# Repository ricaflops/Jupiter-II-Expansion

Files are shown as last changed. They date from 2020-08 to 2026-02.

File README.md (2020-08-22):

# Jupiter-II Expansion
An Expansion board for the [Jupiter-II](https://github.com/ricaflops/Jupiter-II) computer

## Expands Jupiter-II with
- Video color: 16 colors, RGB output
- Programmable Sound Generator
- 128K RAM: paged
- 16K ROM: FORTH vocabulary extension
- Serial Interface

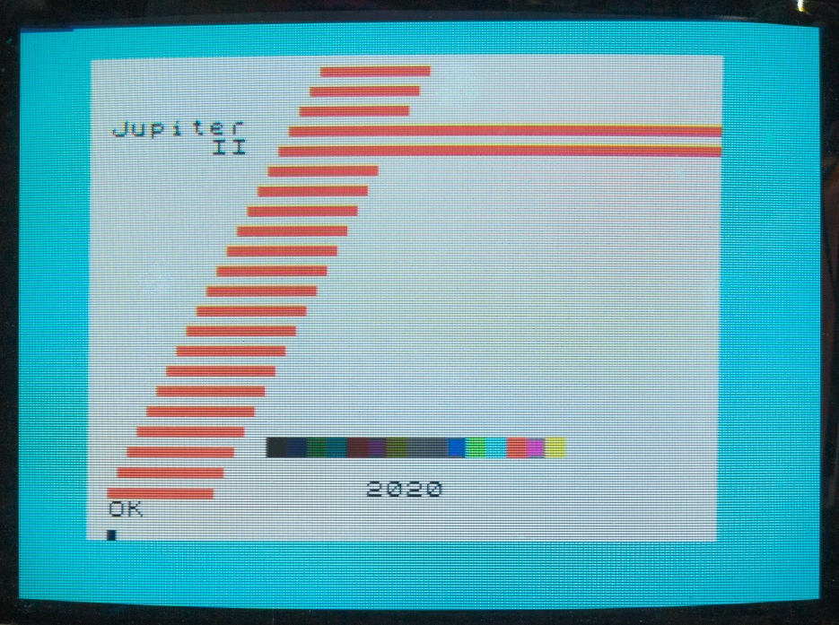
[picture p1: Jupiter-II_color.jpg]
Jupiter-II Color Screen


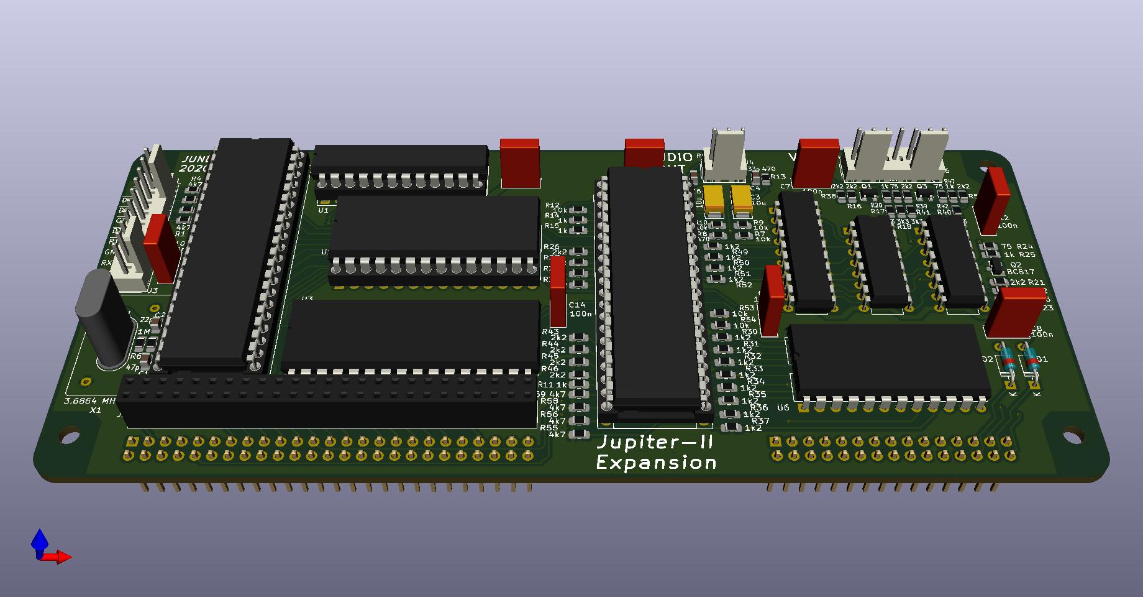
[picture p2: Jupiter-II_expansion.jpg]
Jupiter-II Expansion KiCAD 3D view


## FORTH code examples

### Colors
```
CYAN BORDER ( Change screen border color )
WHITE PAPER ( Set char background color )
BLUE DARK INK ( Set char foreground color ) 

: COLORBAR
  CLS 10 8 AT 16 0
  DO
   I INK 144 EMIT
  LOOP 
  BLACK INK
  ;
COLORBAR ( Show a colorfull bar )
```

### Memory/Screen/Font Paging
```
0 FONT  ( select alternative character set )
1 FONT  ( select original character set )

0 SCREEN ( select screen page 0 )
1 SCREEN ( select screen page 1 )

0 MPAGE ( select memory page 0 )
3 MPAGE ( select memory page 3 )
```

### Sounds
```
: PING
  200 0 PSG!
  254 7 PSG!
  16 8 PSG!
  20 12 PSG!
  1 13 PSG!
;

: SHOT
  8 6 PSG!
  247 7 PSG!
  16 8 PSG!
  20 12 PSG!
  1  13 PSG!
;
```

### Serial Comm Port
8 data bits, 1 stop bit, no parity.
```
CREATE BUFFER 256 ALLOT ( Create and Allocate a memory space to work )
: CLRBUF BUFFER 256 32 FILL ; ( Clear Buffer )
: PRTBUF CR 256 0 DO BUFFER I + EMIT LOOP CR ; ( Print Buffer )

9600 BAUD     ( set communication baud rate )
CLRBUF        ( Clear Buffer )
BUFFER 256 RX ( Receive 256 bytes from serial line )
PRTBUF        ( View received data )
BUFFER 256 TX ( Transmit 256 bytes over serial line )
```
*Note: use Space key to abort communication if needed*

# Extra FORTH vocabulary
The extended vocabulary is copied from XROM to a unused 1K RAM area at $3000-$33FF of Jupiter-II during initialization.
That allows safe memory paging while keeping the extra Words accessible.

### Standard FORTH words

```
COUNT ( addr -- addr+1 c )  Extract String length
+! ( n addr -- )  Add 'n' to 'addr' variable
? ( addr -- )  Print variable value
CMOVE ( addr1 addr2 n -- )  Copy 'n' bytes from 'addr1' to 'addr2'
FILL  ( addr n c -- )  Fill 'n' bytes with 'c' starting from 'addr'
DEPTH ( -- n )  Data Stack Depth
HEX   ( -- )  Set numeric base to Hexadecimal
```

### Programmable Sound Generator

```
PSG! ( c reg -- ) Write 'c' to PSG register 'reg'
PSG@ ( reg -- c ) Read PSG register 'reg' contents
```

### Colors

```
BORDER ( c -- ) Set screen BORDER to color 'c' , 0 to 15
INK    ( c -- ) Set character INK to color 'c' , 0 to 15
PAPER  ( c -- ) Set character PAPER to color 'c' , 0 to 15
BLACK  ( -- c ) Stack color code for Black
GREY   ( -- c ) Stack color code for Grey
BLUE   ( -- c ) Stack color code for Blue
GREEN  ( -- c ) Stack color code for Green
CYAN   ( -- c ) Stack color code for Cyan
RED    ( -- c ) Stack color code for Red
PURPLE ( -- c ) Stack color code for Purple
YELLOW ( -- c ) Stack color code for Yellow
WHITE  ( -- c ) Stack color code for White
DARK   ( c1 -- c2 ) Change color code on stack to a darker tone
```

### Serial Communication
8 data bits, 1 stop bit, no parity.

```
BAUD ( n --  )  Set UART to Baud rate 'n'
TX ( addr n --  )  Transmit 'n' bytes starting from 'addr' to serial line
RX ( addr n --  )  Receive 'n' bytes from serial line to memory 'addr'
```

Avoid transfering to/from video RAM using video circuit priority addressing. That prevents transfer speeds above 1200 bauds.
- Video RAM from $2400 to $27FF. Use mirror addressing $2000 to $23FF instead (CPU priority).
- Character Genrator RAM from $2C00 to $2FFF. Use mirror addressing $2800 to $2BFF instead (CPU priority).

*Note: Character Generator RAM is write only*

### Memory Paging
```
MPAGE  ( c -- ) Select memory page 'c' , 0 to 3
SCREEN ( c -- ) Select Screen page 'c' , 0 or 1
FONT   ( c -- ) Select character set 'c' , 0 or 1
```
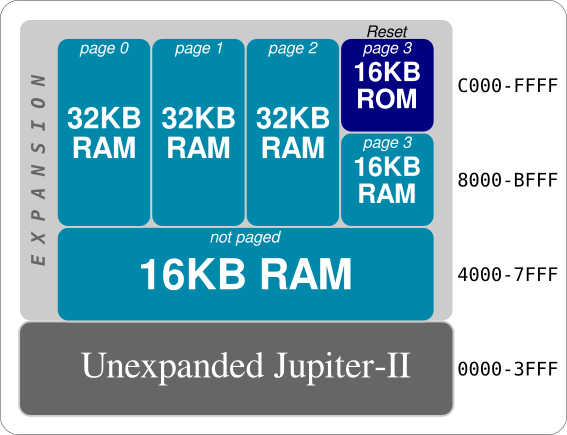
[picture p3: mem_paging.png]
Memry Paging


*Note: System resets to page 3*

## Programmable Sound Generator Registers
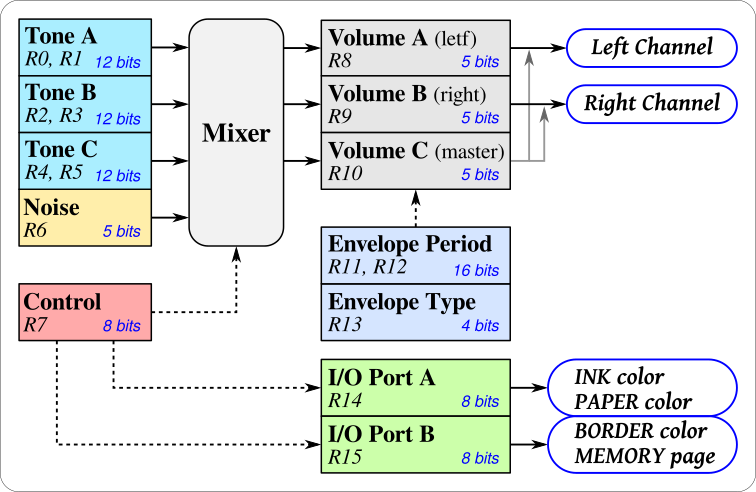
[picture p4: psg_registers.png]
Programmable Sound Generator Registers


```
   bits: 76543210 76543210
  R1 R0: ----tttt tttttttt : Tone generator A period (12-bits) 0-4095
  R3 R2: ----tttt tttttttt : Tone generator B period (12-bits) 0-4095
  R5 R4: ----tttt tttttttt : Tone generator C period (12-bits) 0-4095
     R6:          ---ttttt : Noise generator period  (5-bits)  0-31
     R7:          ppcbaCBA : I/O port and sound channel enablers
     R8:          ---Mvvvv : Channel A Volume (v) and Envelope Mode (M)
     R9:          ---Mvvvv : Channel B Volume (v) and Envelope Mode (M)
    R10:          ---Mvvvv : Channel C Volume (v) and Envelope Mode (M)
R12 R11: tttttttt tttttttt : Envelope period (16-bits) 0-65535
    R13:          ----calh : Envelope Shape: Continue (c), Attack (a), Alternate(l), Hold (h)
    R14:          dddddddd : I/O Port-A data
    R15:          dddddddd : I/O Port-B data
```

**R0..R6**: Tone and Noise Period (Frequency) settings<br/>
> t = 203125 / f , where f is the desirable frequency in Hz<br/>
> Tone Range: 49.6 Hz to 203.1 kHz (0..4095)<br/>
> Noise Range: 6.55 kHz to 293.1 kHz (0..31)<br/>

**R7**: Tone and Noise Mixer and I/O Ports direction<br/>
- bit0: when 0 enables tone A on channel A, 1 disables it
- bit1: when 0 enables tone B on channel B, 1 disables it
- bit2: when 0 enables tone C on channel C, 1 disables it
- bit3: when 0 enables Noise on channel A, 1 disables it
- bit4: when 0 enables Noise on channel B, 1 disables it
- bit5: when 0 enables Noise on channel C, 1 disables it
- bit6: when 0 set digital Port-A as input, 1 set it as output
- bit7: when 0 set digital Port-B as input, 1 set it as output<br/>

**R8..R10**: Channel volume<br/>
- bit4  : when 0 volume is fixed, when 1 volume is Envelope controlled
- bit3-0: Fixed volume value (0-31)<br/>

**R11, R12**: Envelope period<br/>
> t = s / 78.769e-6 , where s is the desirable period in seconds<br/>
> Period range: 78.8 us to 5.16 seconds<br/>

**R13**: Envelope Shape combination<br/>
- bit3: Continue: when 1 follows Hold setting, when 0 resets down after one cycle
- bit2: Attack: when 1 attack ramps up, when 0 ramps down
- bit1: Alternate: when 1 envelope shape reverses on each cycle (up/down)
- bit0: Hold: when 1 limits to one cycle and sustain final value<br/>

**R14, R15**: Digital I/O Port data<br/>
- Port A (register 14) controls PAPER and INK colors
- Port B (register 15) controls BORDER color and paging<br/>

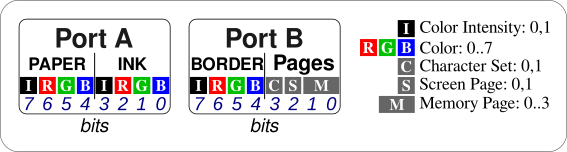
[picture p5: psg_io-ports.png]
Programmable Sound Generator Ports


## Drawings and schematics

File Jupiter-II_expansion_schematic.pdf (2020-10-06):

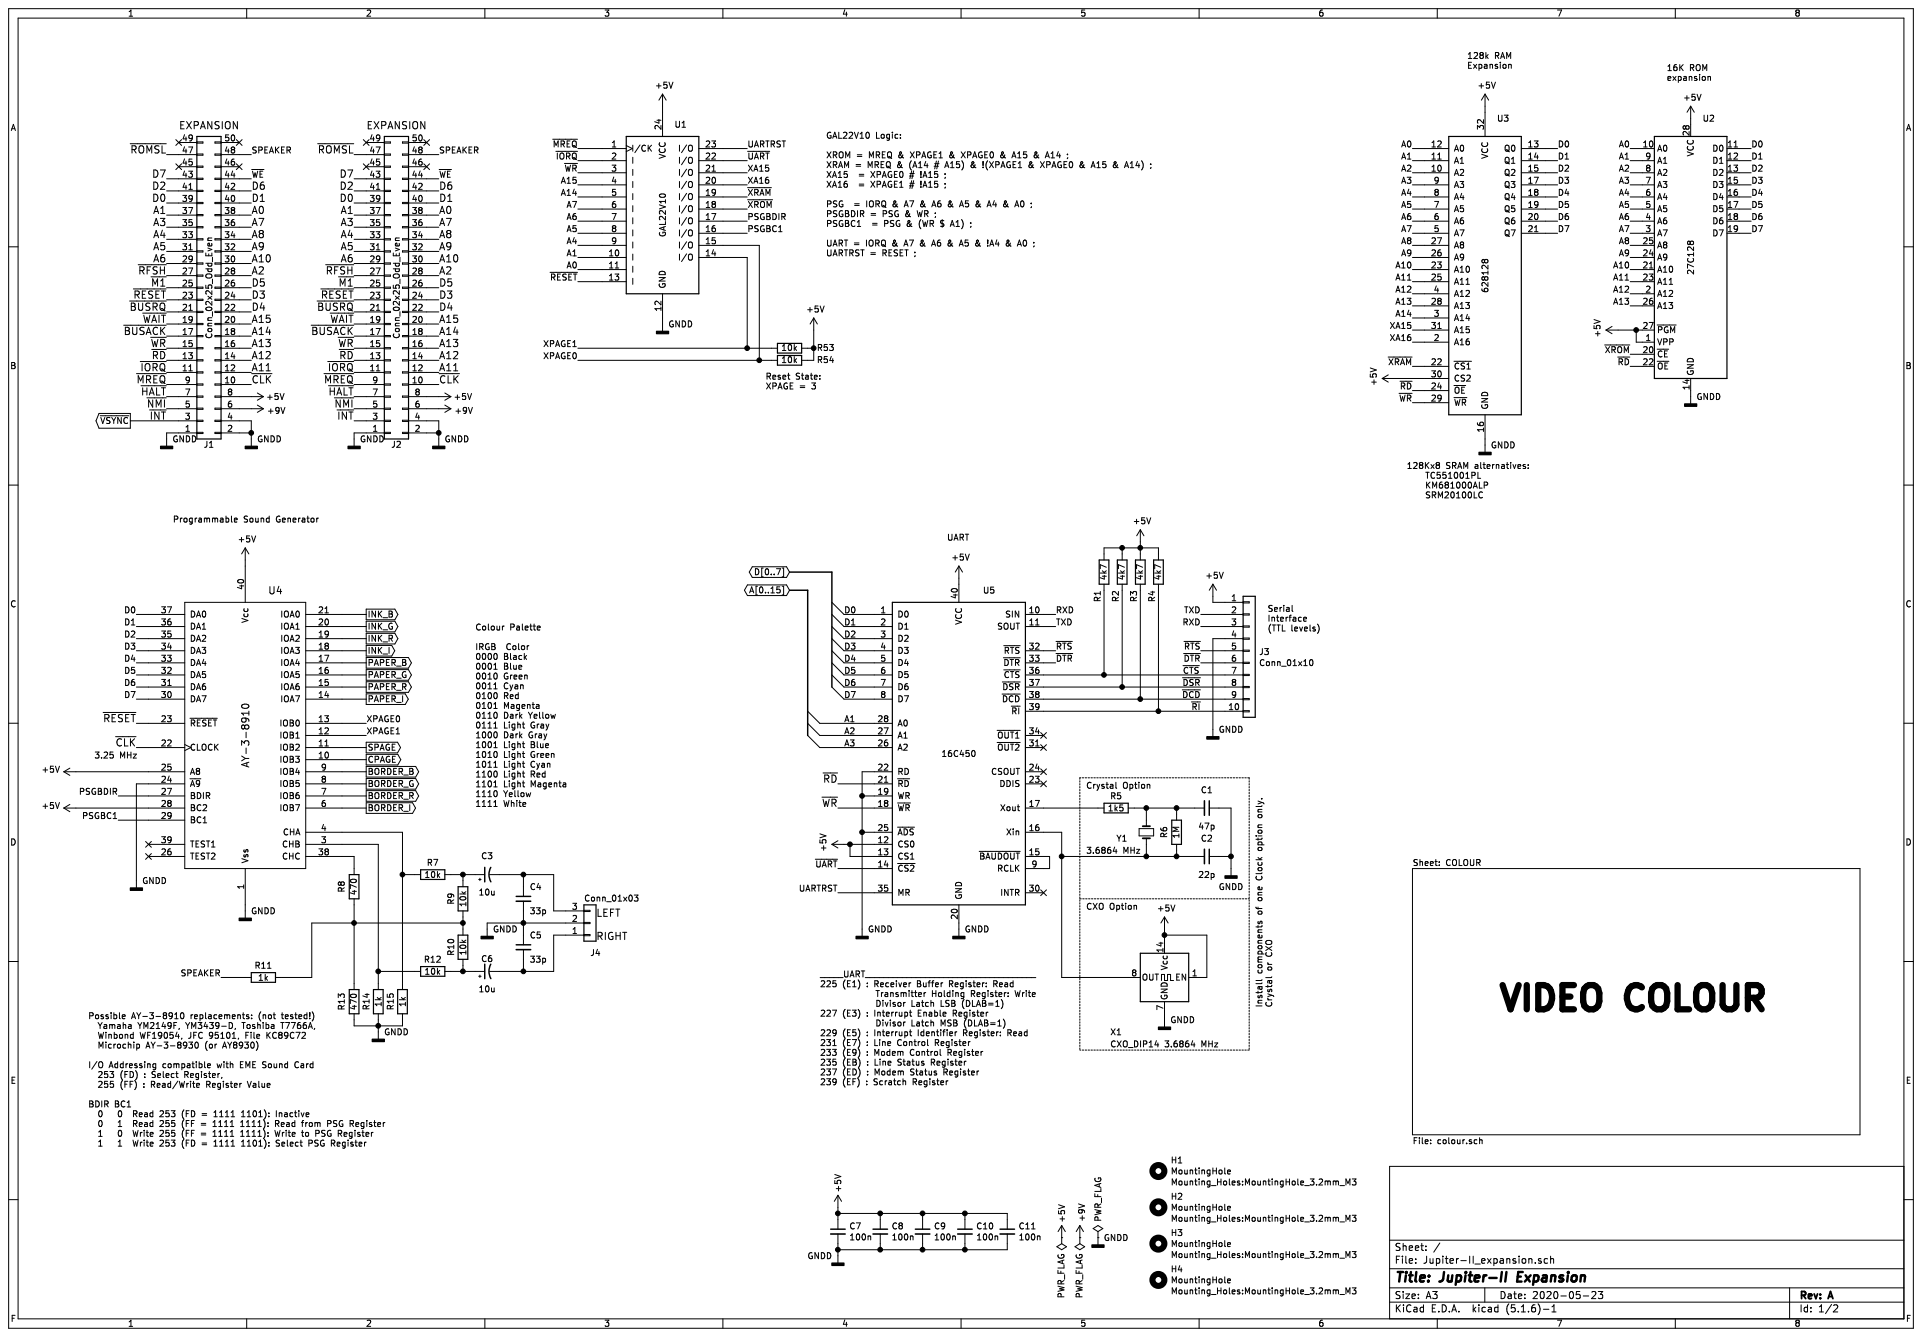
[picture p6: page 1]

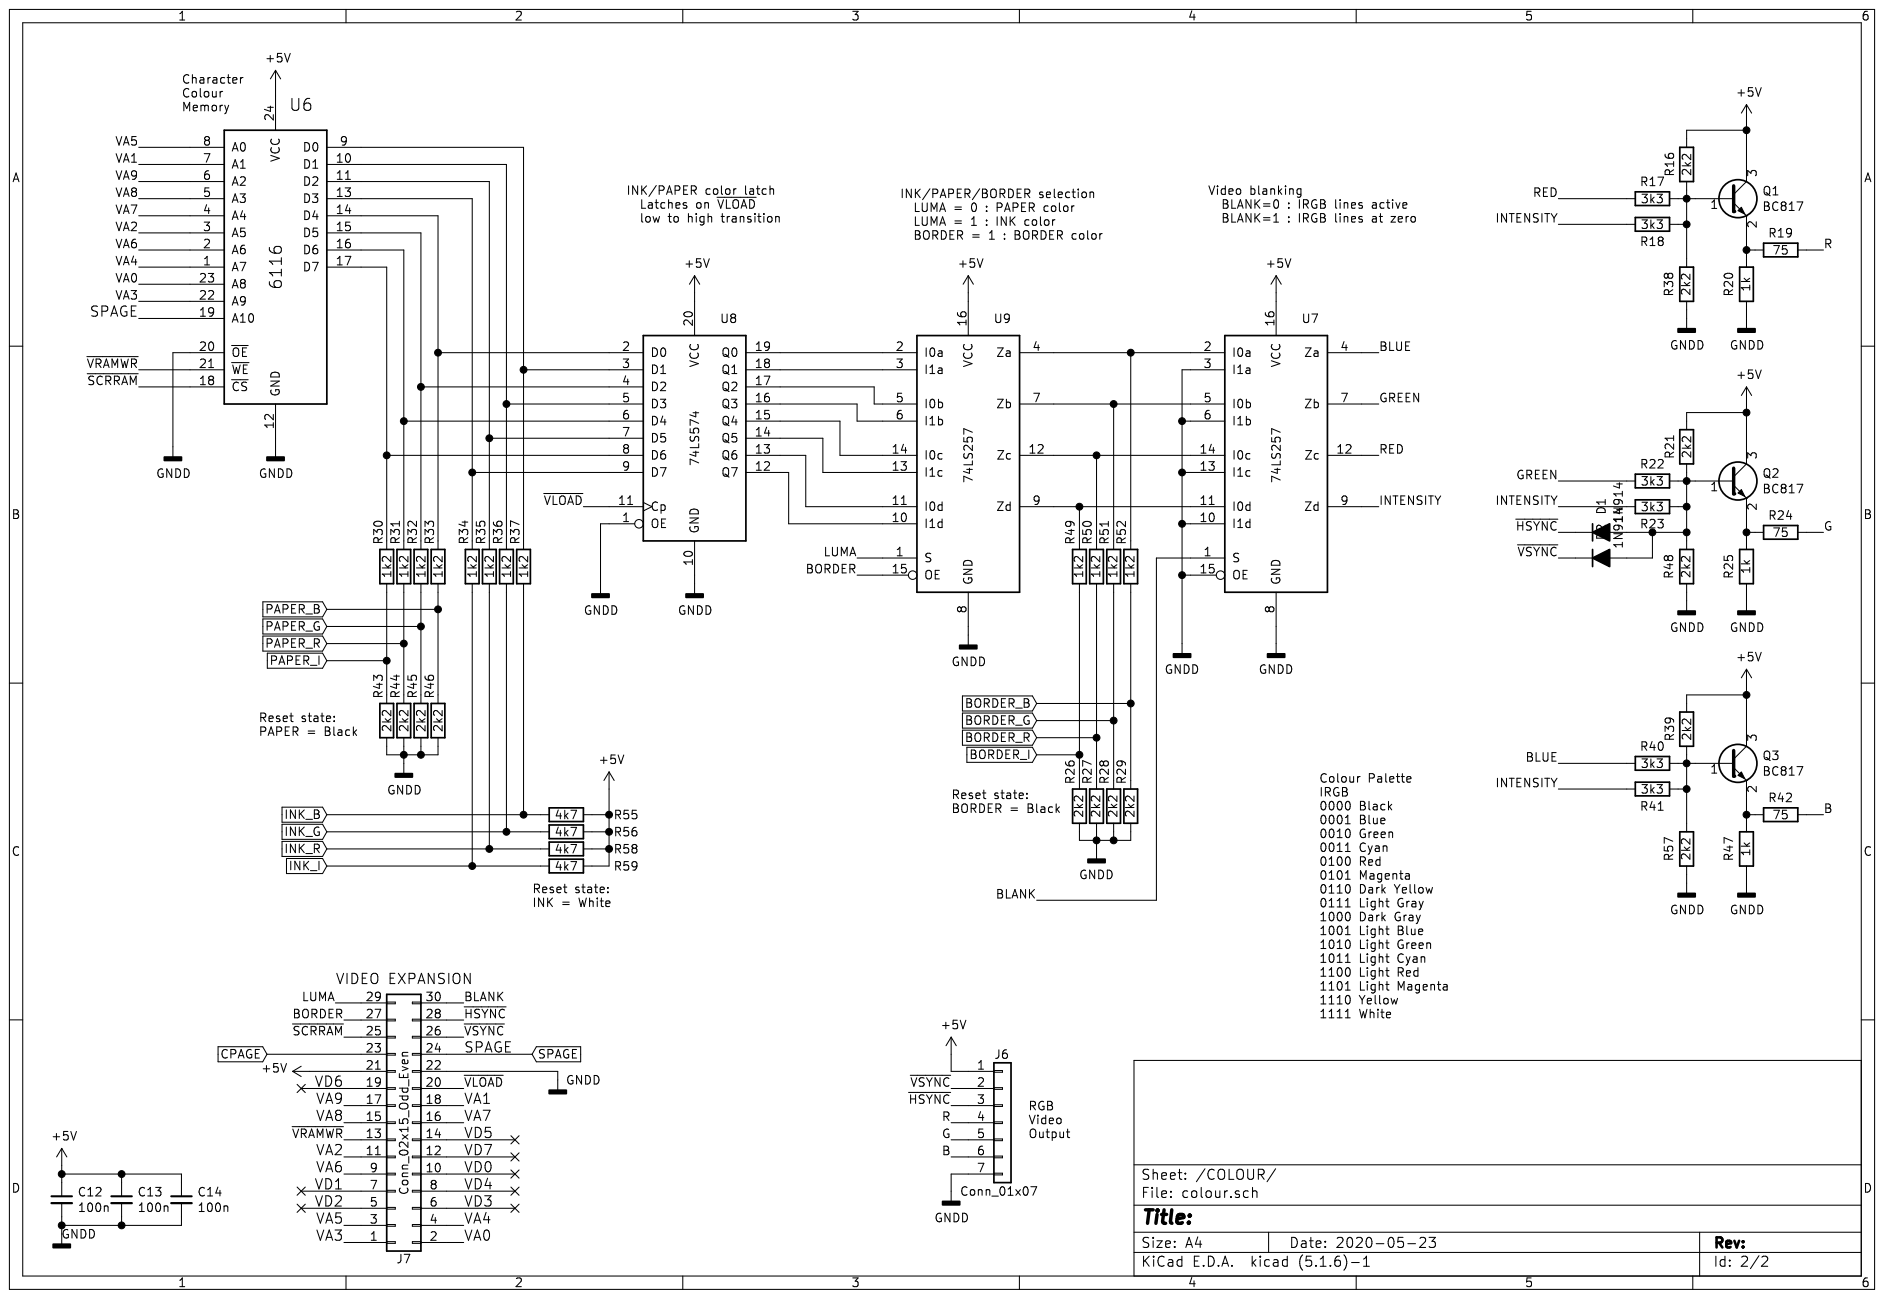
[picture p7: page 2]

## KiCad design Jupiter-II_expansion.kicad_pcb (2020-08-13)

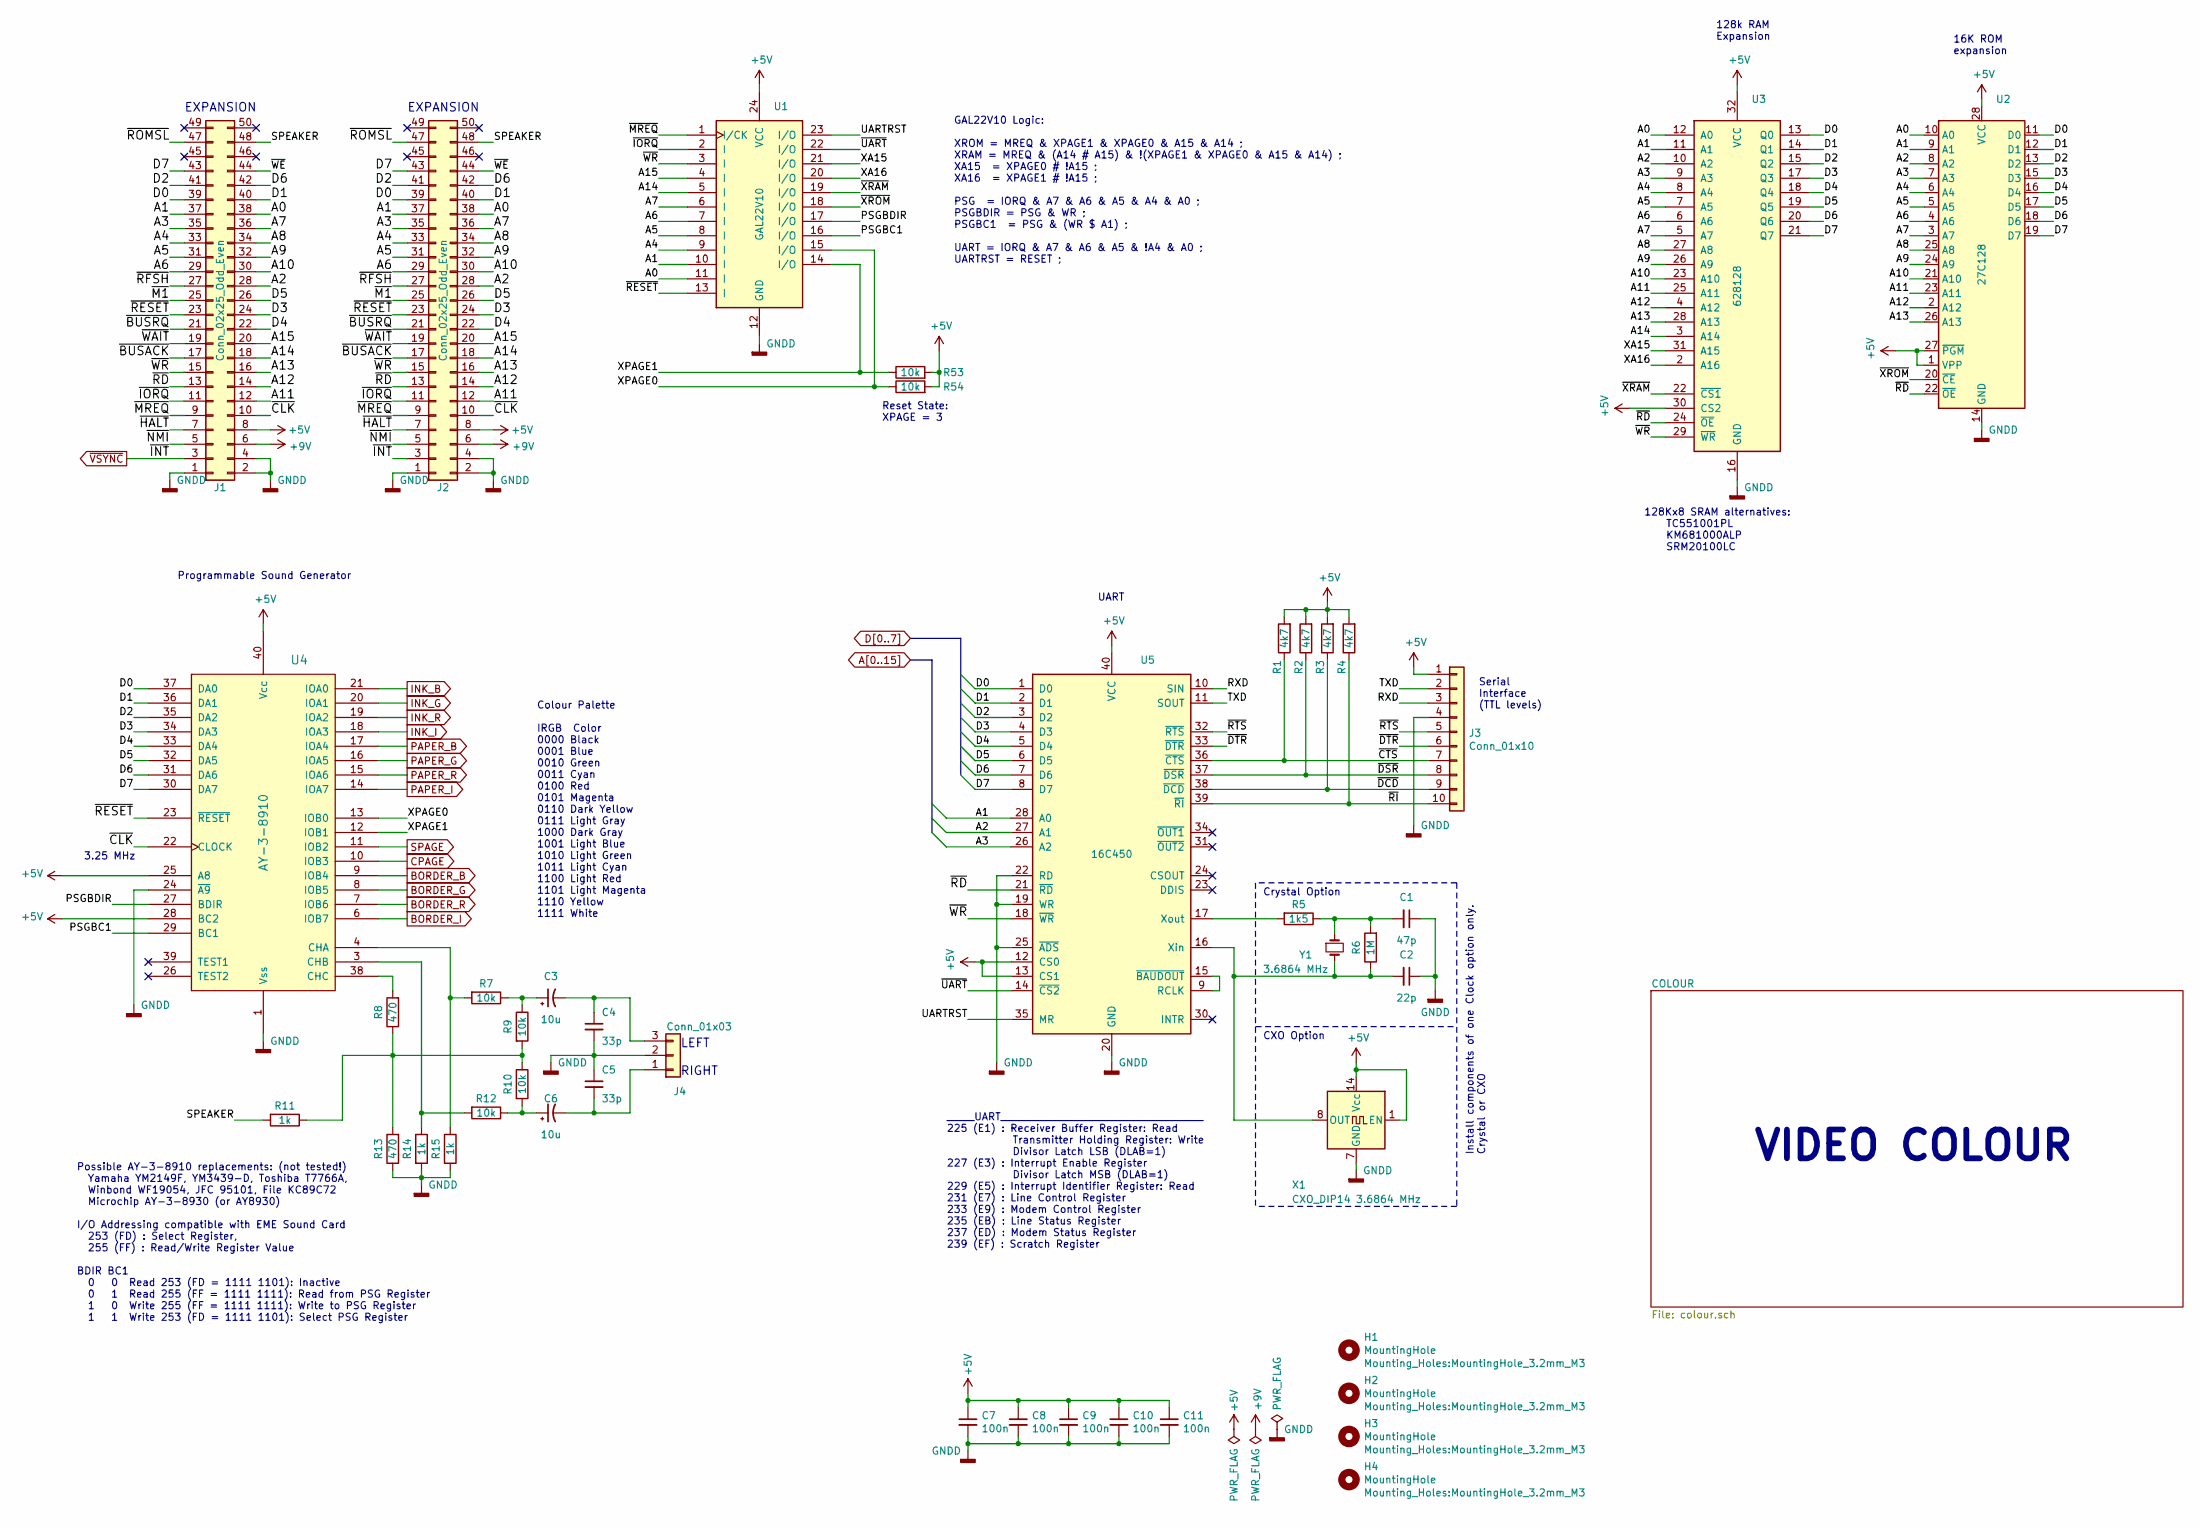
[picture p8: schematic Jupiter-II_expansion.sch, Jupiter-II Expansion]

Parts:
C1: 47p; C_0805_2012Metric_Pad1.15x1.40mm_HandSolder
C2: 22p; C_0805_2012Metric_Pad1.15x1.40mm_HandSolder
C3, C6: 10u; CP_EIA-6032-15_Kemet-U_Pad2.25x2.35mm_HandSolder
C4, C5: 33p; C_0805_2012Metric_Pad1.15x1.40mm_HandSolder
C7, C8, C9, C10, C11: 100n; C_Rect_L7.0mm_W2.5mm_P5.00mm
H1, H2, H3, H4: MountingHole; MountingHole_3.2mm_M3
J1: Conn_02x25_Odd_Even; PinHeader_2x25_P2.54mm_Vertical
J2: Conn_02x25_Odd_Even; PinSocket_2x25_P2.54mm_Vertical
J3: Conn_01x10; Molex_KK-254_AE-6410-10A_1x10_P2.54mm_Vertical
J4: Conn_01x03; Molex_KK-254_AE-6410-03A_1x03_P2.54mm_Vertical
R1, R2, R3, R4: 4k7; R_0805_2012Metric_Pad1.15x1.40mm_HandSolder
R5: 1k5; R_0805_2012Metric_Pad1.15x1.40mm_HandSolder
R6: 1M; R_0805_2012Metric_Pad1.15x1.40mm_HandSolder
R7, R9, R10, R12, R53, R54: 10k; R_0805_2012Metric_Pad1.15x1.40mm_HandSolder
R8, R13: 470; R_0805_2012Metric_Pad1.15x1.40mm_HandSolder
R11, R14, R15: 1k; R_0805_2012Metric_Pad1.15x1.40mm_HandSolder
U1: GAL22V10; DIP-24_W7.62mm_Socket
U2: 27C128; DIP-28_W15.24mm
U3: 628128; DIP-32_W15.24mm
U4: AY-3-8910; DIP-40_W15.24mm_Socket
U5: 16C450; DIP-40_W15.24mm_Socket
X1: CXO_DIP14 3.6864 MHz; Oscillator_DIP-14
Y1: 3.6864 MHz; Crystal_HC18-U_Vertical

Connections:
+5V: C7.1, C8.1, C9.1, C10.1, C11.1, J1.8, J2.8, J3.1, R1.2, R2.2, R3.2, R4.2, R53.2, R54.2, U1.24 (VCC), U2.1 (VPP), U2.27 (~PGM), U2.28 (VCC), U3.30 (CS2), U3.32 (VCC), U4.25 (A8), U4.28 (BC2), U4.40 (Vcc), U5.12 (CS0), U5.13 (CS1), U5.40 (VCC), X1.1 (EN), X1.14 (Vcc); also elsewhere on the board
+9V: J1.6, J2.6
/PSGBC1: U1.16 (I/O), U4.29 (BC1)
/PSGBDIR: U1.17 (I/O), U4.27 (BDIR)
/RXD: J3.3, U5.10 (SIN)
/SPEAKER: J1.48, J2.48, R11.2
/TXD: J3.2, U5.11 (SOUT)
/UARTRST: U1.23 (I/O), U5.35 (MR)
/XA15: U1.21 (I/O), U3.31 (A15)
/XA16: U1.20 (I/O), U3.2 (A16)
/XPAGE0: R54.1, U1.15 (I/O), U4.13 (IOB0)
/XPAGE1: R53.1, U1.14 (I/O), U4.12 (IOB1)
/~BUSACK: J1.17, J2.17
/~BUSRQ: J1.21, J2.21
/~CLK: J1.10, J2.10, U4.22 (CLOCK)
/~CTS: J3.7, R1.1, U5.36 (~CTS)
/~DCD: J3.9, R3.1, U5.38 (~DCD)
/~DSR: J3.8, R2.1, U5.37 (~DSR)
/~DTR: J3.6, U5.33 (~DTR)
/~HALT: J1.7, J2.7
/~IORQ: J1.11, J2.11, U1.2 (I)
/~M1: J1.25, J2.25
/~MREQ: J1.9, J2.9, U1.1 (I/CK)
/~NMI: J1.5, J2.5
/~RD: J1.13, J2.13, U2.22 (~OE), U3.24 (~OE), U5.21 (~RD)
/~RESET: J1.23, J2.23, U1.13 (I), U4.23 (~RESET)
/~RFSH: J1.27, J2.27
/~RI: J3.10, R4.1, U5.39 (~RI)
/~ROMSL: J1.47, J2.47
/~RTS: J3.5, U5.32 (~RTS)
/~UART: U1.22 (I/O), U5.14 (~CS2)
/~WAIT: J1.19, J2.19
/~WE: J1.44, J2.44
/~WR: J1.15, J2.15, U1.3 (I), U3.29 (~WR), U5.18 (~WR)
/~XRAM: U1.19 (I/O), U3.22 (~CS1)
/~XROM: U1.18 (I/O), U2.20 (~CE)
A0: J1.38, J2.38, U1.11 (I), U2.10 (A0), U3.12 (A0)
A1: J1.37, J2.37, U1.10 (I), U2.9 (A1), U3.11 (A1), U5.28 (A0)
A2: J1.28, J2.28, U2.8 (A2), U3.10 (A2), U5.27 (A1)
A3: J1.35, J2.35, U2.7 (A3), U3.9 (A3), U5.26 (A2)
A4: J1.33, J2.33, U1.9 (I), U2.6 (A4), U3.8 (A4)
A5: J1.31, J2.31, U1.8 (I), U2.5 (A5), U3.7 (A5)
A6: J1.29, J2.29, U1.7 (I), U2.4 (A6), U3.6 (A6)
A7: J1.36, J2.36, U1.6 (I), U2.3 (A7), U3.5 (A7)
A8: J1.34, J2.34, U2.25 (A8), U3.27 (A8)
A9: J1.32, J2.32, U2.24 (A9), U3.26 (A9)
A10: J1.30, J2.30, U2.21 (A10), U3.23 (A10)
A11: J1.12, J2.12, U2.23 (A11), U3.25 (A11)
A12: J1.14, J2.14, U2.2 (A12), U3.4 (A12)
A13: J1.16, J2.16, U2.26 (A13), U3.28 (A13)
A14: J1.18, J2.18, U1.5 (I), U3.3 (A14)
A15: J1.20, J2.20, U1.4 (I)
BORDER_B: U4.9 (IOB4); also elsewhere on the board
BORDER_G: U4.8 (IOB5); also elsewhere on the board
BORDER_I: U4.6 (IOB7); also elsewhere on the board
BORDER_R: U4.7 (IOB6); also elsewhere on the board
CPAGE: U4.10 (IOB3); also elsewhere on the board
D0: J1.39, J2.39, U2.11 (D0), U3.13 (Q0), U4.37 (DA0), U5.1 (D0)
D1: J1.40, J2.40, U2.12 (D1), U3.14 (Q1), U4.36 (DA1), U5.2 (D1)
D2: J1.41, J2.41, U2.13 (D2), U3.15 (Q2), U4.35 (DA2), U5.3 (D2)
D3: J1.24, J2.24, U2.15 (D3), U3.17 (Q3), U4.34 (DA3), U5.4 (D3)
D4: J1.22, J2.22, U2.16 (D4), U3.18 (Q4), U4.33 (DA4), U5.5 (D4)
D5: J1.26, J2.26, U2.17 (D5), U3.19 (Q5), U4.32 (DA5), U5.6 (D5)
D6: J1.42, J2.42, U2.18 (D6), U3.20 (Q6), U4.31 (DA6), U5.7 (D6)
D7: J1.43, J2.43, U2.19 (D7), U3.21 (Q7), U4.30 (DA7), U5.8 (D7)
GNDD: C1.1, C2.1, C4.2, C5.1, C7.2, C8.2, C9.2, C10.2, C11.2, J1.1, J1.2, J1.4, J2.1, J2.2, J2.4, J3.4, J4.2, R13.1, R14.2, R15.2, U1.12 (GND), U2.14 (GND), U3.16 (GND), U4.1 (Vss), U4.24 (~A9), U5.19 (WR), U5.20 (GND), U5.22 (RD), U5.25 (~ADS), X1.7 (GND); also elsewhere on the board
INK_B: U4.21 (IOA0); also elsewhere on the board
INK_G: U4.20 (IOA1); also elsewhere on the board
INK_I: U4.18 (IOA3); also elsewhere on the board
INK_R: U4.19 (IOA2); also elsewhere on the board
unnamed: C1.2, R5.1, R6.2, Y1.1
unnamed: C2.2, R6.1, U5.16 (Xin), X1.8 (OUT), Y1.2
unnamed: C3.1, R7.1, R9.1
unnamed: C3.2, C4.1, J4.3
unnamed: C5.2, C6.2, J4.1
unnamed: C6.1, R10.2, R12.1
unnamed: R5.2, U5.17 (Xout)
unnamed: R8.2, U4.38 (CHC)
unnamed: R8.1, R9.2, R10.1, R11.1, R13.2
unnamed: R12.2, R14.1, U4.3 (CHB)
unnamed: R7.2, R15.1, U4.4 (CHA)
unnamed: U5.9 (RCLK), U5.15 (~BAUDOUT)
PAPER_B: U4.17 (IOA4); also elsewhere on the board
PAPER_G: U4.16 (IOA5); also elsewhere on the board
PAPER_I: U4.14 (IOA7); also elsewhere on the board
PAPER_R: U4.15 (IOA6); also elsewhere on the board
SPAGE: U4.11 (IOB2); also elsewhere on the board
~VSYNC: J1.3, J2.3

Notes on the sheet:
Programmable Sound Generator
Possible AY-3-8910 replacements: (not tested!) Yamaha YM2149F, YM3439-D, Toshiba T7766A, Winbond WF19054, JFC 95101, File KC89C72 Microchip AY-3-8930 (or AY8930) I/O Addressing compatible with EME Sound Card 253 (FD) : Select Register, 255 (FF) : Read/Write Register Value BDIR BC1 0 0 Read 253 (FD 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
LEFT RIGHT
GAL22V10 Logic: XROM = MREQ & XPAGE1 & XPAGE0 & A15 & A14 ; XRAM = MREQ & (A14 # A15) & !(XPAGE1 & XPAGE0 & A15 & A14) ; XA15 = XPAGE0 # !A15 ; XA16 = XPAGE1 # !A15 ; PSG = IORQ & A7 & A6 & A5 & A4 & A0 ; PSGBDIR = PSG & WR ; PSGBC1 = PSG & (WR $ A1) ; UART = IORQ & A7 & A6 & A5 & !A4 & A0 ; UARTRS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
128k RAM Expansion
16K ROM expansion
3.25 MHz
EXPANSION
VIDEO COLOUR
UART
CXO Option
Crystal Option
Serial Interface (TTL levels)
Install components of one Clock option only. Crystal or CXO
_____UART_____________________________________ 225 (E1) : Receiver Buffer Register: Read Transmitter Holding Register: Write Divisor Latch LSB (DLAB=1) 227 (E3) : Interrupt Enable Register Divisor Latch MSB (DLAB=1) 229 (E5) : Interrupt Identifier Register: Read 231 (E7) : Line Control Register 233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
128Kx8 SRAM alternatives: TC551001PL KM681000ALP SRM20100LC
Colour Palette IRGB Color 0000 Black 0001 Blue 0010 Green 0011 Cyan 0100 Red 0101 Magenta 0110 Dark Yellow 0111 Light Gray 1000 Dark Gray 1001 Light Blue 1010 Light Green 1011 Light Cyan 1100 Light Red 1101 Light Magenta 1110 Yellow 1111 White
Reset State: XPAGE = 3

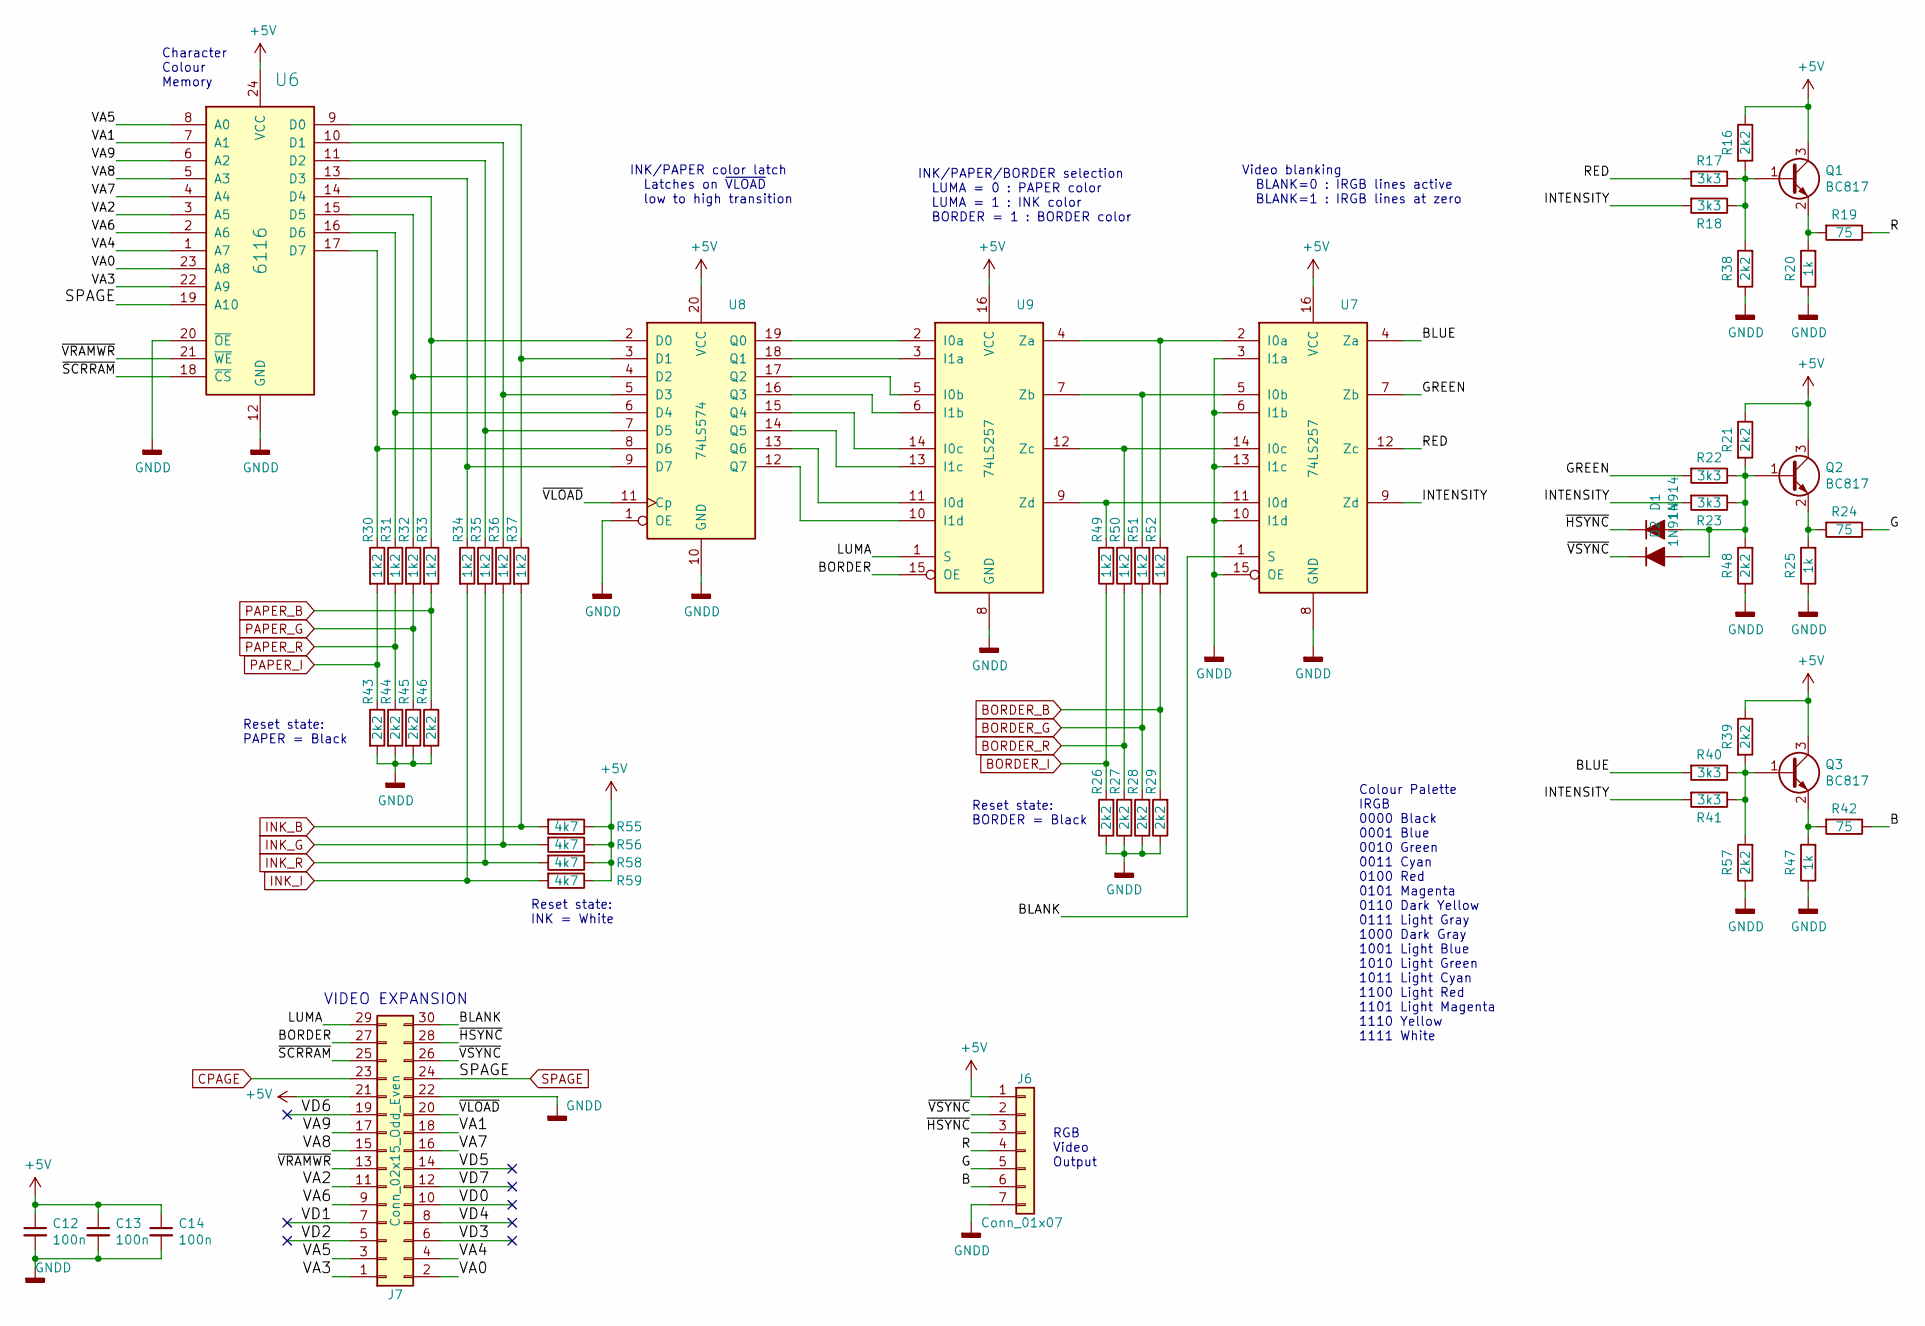
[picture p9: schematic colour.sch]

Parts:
C12, C13, C14: 100n; C_Rect_L7.0mm_W2.5mm_P5.00mm
D1, D2: 1N914; D_DO-35_SOD27_P7.62mm_Horizontal
J6: Conn_01x07; Molex_KK-254_AE-6410-07A_1x07_P2.54mm_Vertical
J7: Conn_02x15_Odd_Even; PinHeader_2x15_P2.54mm_Vertical
Q1, Q2, Q3: BC817; SOT-23
R16, R21, R26, R27, R28, R29, R38, R39, R43, R44, R45, R46, R48, R57: 2k2; R_0805_2012Metric_Pad1.15x1.40mm_HandSolder
R17, R18, R22, R23, R40, R41: 3k3; R_0805_2012Metric_Pad1.15x1.40mm_HandSolder
R19, R24, R42: 75; R_0805_2012Metric_Pad1.15x1.40mm_HandSolder
R20, R25, R47: 1k; R_0805_2012Metric_Pad1.15x1.40mm_HandSolder
R30, R31, R32, R33, R34, R35, R36, R37, R49, R50, R51, R52: 1k2; R_0805_2012Metric_Pad1.15x1.40mm_HandSolder
R55, R56, R58, R59: 4k7; R_0805_2012Metric_Pad1.15x1.40mm_HandSolder
U6: 6116; DIP-24_W15.24mm
U7, U9: 74LS257; DIP-16_W7.62mm
U8: 74LS574; DIP-20_W7.62mm

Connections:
+5V: C12.1, C13.1, C14.1, J6.1, J7.21, Q1.3 (C), Q2.3 (C), Q3.3 (C), R16.1, R21.1, R39.1, R55.1, R56.1, R58.1, R59.1, U6.24 (VCC), U7.16 (VCC), U8.20 (VCC), U9.16 (VCC); also elsewhere on the board
/COLOUR/B: J6.6, R42.1
/COLOUR/BLANK: J7.30, U7.1 (S)
/COLOUR/BLUE: R40.2, U7.4 (Za)
/COLOUR/BORDER: J7.27, U9.15 (OE)
/COLOUR/G: J6.5, R24.1
/COLOUR/GREEN: R22.2, U7.7 (Zb)
/COLOUR/INTENSITY: R18.2, R23.2, R41.2, U7.9 (Zd)
/COLOUR/LUMA: J7.29, U9.1 (S)
/COLOUR/R: J6.4, R19.1
/COLOUR/RED: R17.2, U7.12 (Zc)
/COLOUR/VA0: J7.2, U6.23 (A8)
/COLOUR/VA1: J7.18, U6.7 (A1)
/COLOUR/VA2: J7.11, U6.3 (A5)
/COLOUR/VA3: J7.1, U6.22 (A9)
/COLOUR/VA4: J7.4, U6.1 (A7)
/COLOUR/VA5: J7.3, U6.8 (A0)
/COLOUR/VA6: J7.9, U6.2 (A6)
/COLOUR/VA7: J7.16, U6.4 (A4)
/COLOUR/VA8: J7.15, U6.5 (A3)
/COLOUR/VA9: J7.17, U6.6 (A2)
/COLOUR/VD0: J7.10
/COLOUR/VD1: J7.7
/COLOUR/VD2: J7.5
/COLOUR/VD3: J7.6
/COLOUR/VD4: J7.8
/COLOUR/VD5: J7.14
/COLOUR/VD6: J7.19
/COLOUR/VD7: J7.12
/COLOUR/~HSYNC: D1.1 (K), J6.3, J7.28
/COLOUR/~SCRRAM: J7.25, U6.18 (~CS)
/COLOUR/~VLOAD: J7.20, U8.11 (Cp)
/COLOUR/~VRAMWR: J7.13, U6.21 (~WE)
/COLOUR/~VSYNC: D2.1 (K), J6.2, J7.26
BORDER_B: R29.2, R52.1; also elsewhere on the board
BORDER_G: R28.2, R51.1; also elsewhere on the board
BORDER_I: R26.2, R49.1; also elsewhere on the board
BORDER_R: R27.2, R50.1; also elsewhere on the board
CPAGE: J7.23; also elsewhere on the board
GNDD: C12.2, C13.2, C14.2, J6.7, J7.22, R20.1, R25.1, R26.1, R27.1, R28.1, R29.1, R38.1, R43.2, R44.2, R45.2, R46.2, R47.1, R48.1, R57.1, U6.12 (GND), U6.20 (~OE), U7.3 (I1a), U7.6 (I1b), U7.8 (GND), U7.10 (I1d), U7.13 (I1c), U7.15 (OE), U8.1 (OE), U8.10 (GND), U9.8 (GND); also elsewhere on the board
INK_B: R37.2, R55.2; also elsewhere on the board
INK_G: R36.2, R56.2; also elsewhere on the board
INK_I: R34.2, R59.2; also elsewhere on the board
INK_R: R35.2, R58.2; also elsewhere on the board
unnamed: D1.2 (A), D2.2 (A), Q2.1 (B), R21.2, R22.1, R23.1, R48.2
unnamed: Q1.1 (B), R16.2, R17.1, R18.1, R38.2
unnamed: Q1.2 (E), R19.2, R20.2
unnamed: Q2.2 (E), R24.2, R25.2
unnamed: Q3.1 (B), R39.2, R40.1, R41.1, R57.2
unnamed: Q3.2 (E), R42.2, R47.2
unnamed: R30.1, U6.17 (D7), U8.8 (D6)
unnamed: R31.1, U6.16 (D6), U8.6 (D4)
unnamed: R32.1, U6.15 (D5), U8.4 (D2)
unnamed: R33.1, U6.14 (D4), U8.2 (D0)
unnamed: R34.1, U6.13 (D3), U8.9 (D7)
unnamed: R35.1, U6.11 (D2), U8.7 (D5)
unnamed: R36.1, U6.10 (D1), U8.5 (D3)
unnamed: R37.1, U6.9 (D0), U8.3 (D1)
unnamed: R49.2, U7.11 (I0d), U9.9 (Zd)
unnamed: R50.2, U7.14 (I0c), U9.12 (Zc)
unnamed: R51.2, U7.5 (I0b), U9.7 (Zb)
unnamed: R52.2, U7.2 (I0a), U9.4 (Za)
unnamed: U8.12 (Q7), U9.10 (I1d)
unnamed: U8.13 (Q6), U9.11 (I0d)
unnamed: U8.14 (Q5), U9.13 (I1c)
unnamed: U8.15 (Q4), U9.14 (I0c)
unnamed: U8.16 (Q3), U9.6 (I1b)
unnamed: U8.17 (Q2), U9.5 (I0b)
unnamed: U8.18 (Q1), U9.3 (I1a)
unnamed: U8.19 (Q0), U9.2 (I0a)
PAPER_B: R33.2, R46.1; also elsewhere on the board
PAPER_G: R32.2, R45.1; also elsewhere on the board
PAPER_I: R30.2, R43.1; also elsewhere on the board
PAPER_R: R31.2, R44.1; also elsewhere on the board
SPAGE: J7.24, U6.19 (A10); also elsewhere on the board

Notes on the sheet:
INK/PAPER color latch Latches on ~VLOAD~ low to high transition
Character Colour Memory
Colour Palette IRGB 0000 Black 0001 Blue 0010 Green 0011 Cyan 0100 Red 0101 Magenta 0110 Dark Yellow 0111 Light Gray 1000 Dark Gray 1001 Light Blue 1010 Light Green 1011 Light Cyan 1100 Light Red 1101 Light Magenta 1110 Yellow 1111 White
INK/PAPER/BORDER selection LUMA = 0 : PAPER color LUMA = 1 : INK color BORDER = 1 : BORDER color
Reset state: PAPER = Black
Reset state: INK = White
VIDEO EXPANSION
Reset state: BORDER = Black
Video blanking BLANK=0 : IRGB lines active BLANK=1 : IRGB lines at zero
RGB Video Output

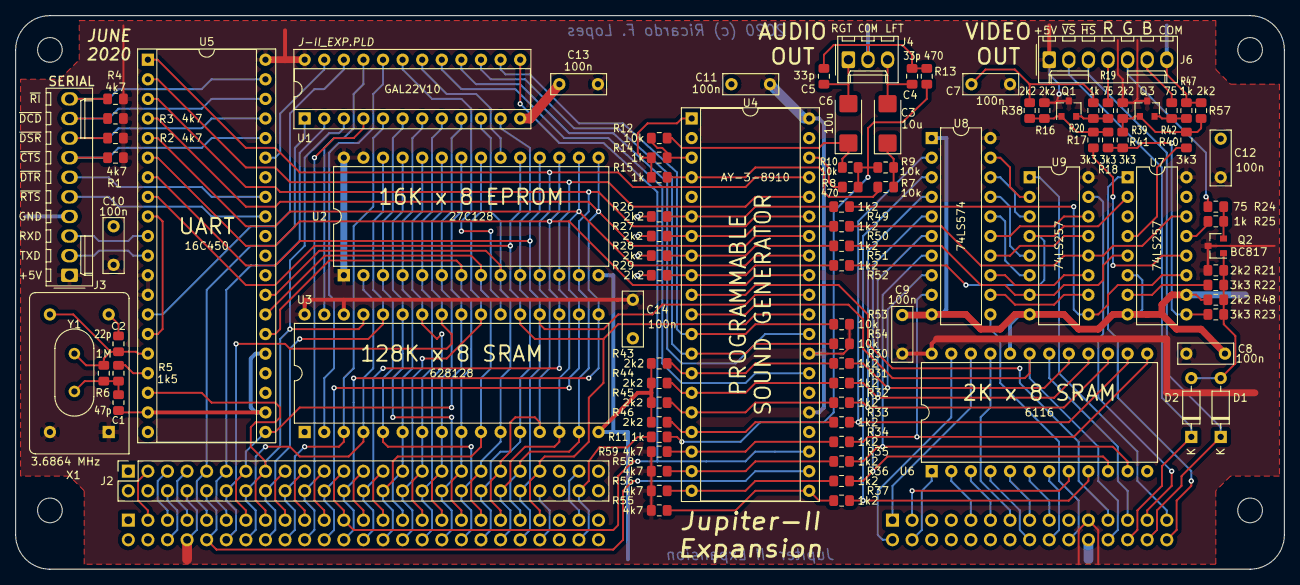
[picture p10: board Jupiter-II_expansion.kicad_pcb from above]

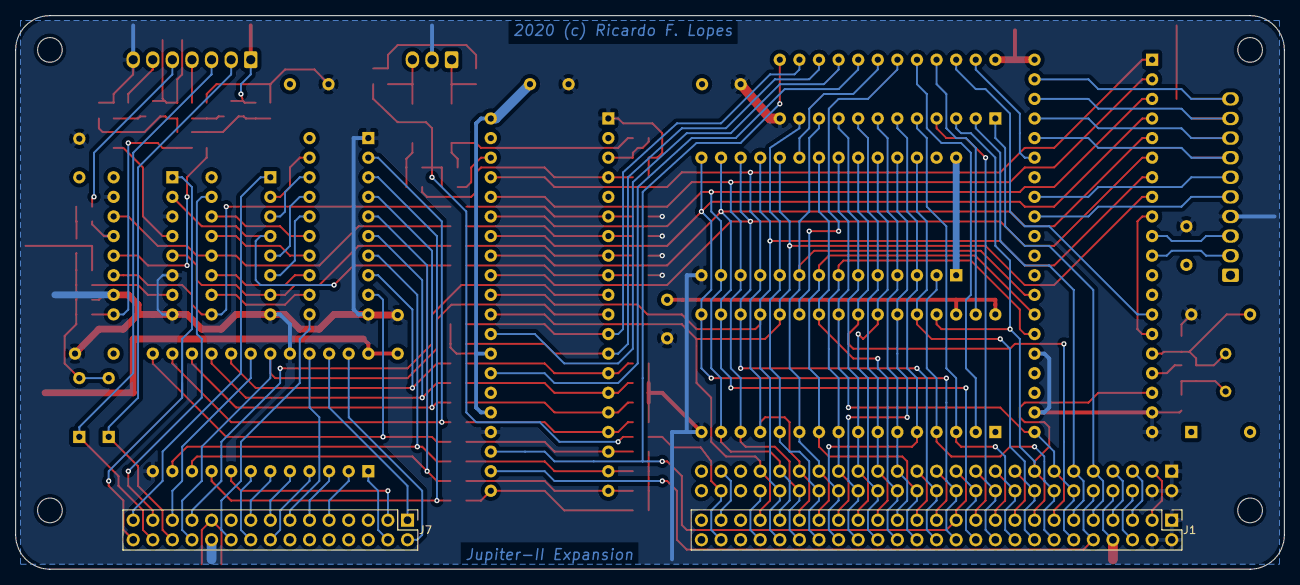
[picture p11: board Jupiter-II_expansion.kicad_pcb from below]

Board: 2 copper layers, 164.5 x 71.8 mm, 99 parts (2 on the bottom side), 139 nets.

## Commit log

2020-08-02 First working version
    Hardware validation
    [Jupiter-II_expansion-B_Cu.gbr, Jupiter-II_expansion-B_Mask.gbr, Jupiter-II_expansion-B_SilkS.gbr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]
2020-08-06 Text corrections
    [Jupiter-II_expansion.sch, colour.sch]
2020-08-13 Corrected missing connections on XROM
    Corrected missing connections on XROM pins 1 and 27
    [Jupiter-II_expansion-B_Cu.gbr, Jupiter-II_expansion-B_Mask.gbr, Jupiter-II_expansion-B_SilkS.gbr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]
2020-10-06 Added missing library
    Added missing library and PDF schematic
    [Jupiter-II_expansion.sch]
